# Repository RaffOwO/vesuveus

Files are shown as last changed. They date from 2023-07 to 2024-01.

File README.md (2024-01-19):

<p align="center" style="box-shadow: 0px 4px 8px rgba(0, 0, 0, 0.1);">
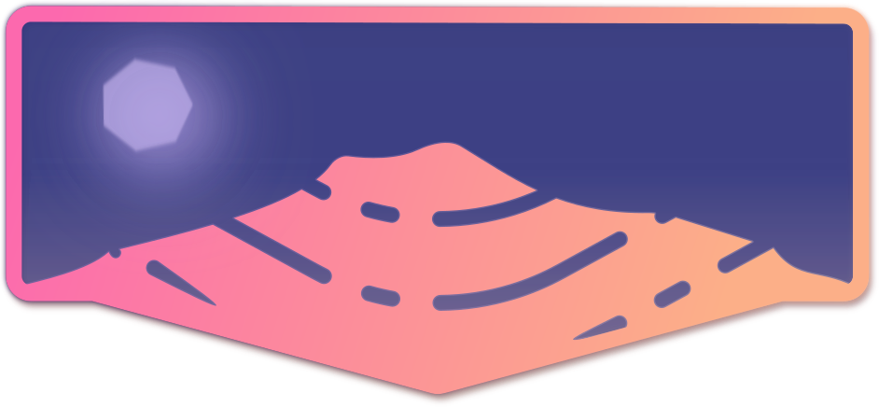
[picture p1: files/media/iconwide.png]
vesuveus keyboard
  
</p>

# Vesuveus - *Small*, yet *Mighty*, Mechanical Keyboard

Hey there! I present to you the Vesuveus, a small, ergonomic mechanical keyboard! 
It's carefully designed to be your trusty sidekick for every task, whether you're coding, designing, gaming or just having some typing fun.

This little wonder is heavily inspired by the [atreus](https://shop.keyboard.io/products/keyboardio-atreus), the _alice_
and many amazing works of the [community](https://reddit.com/r/ergomechkeyboards). 

  <p align="center" style="box-shadow: 0px 4px 8px rgba(0, 0, 0, 0.1);">
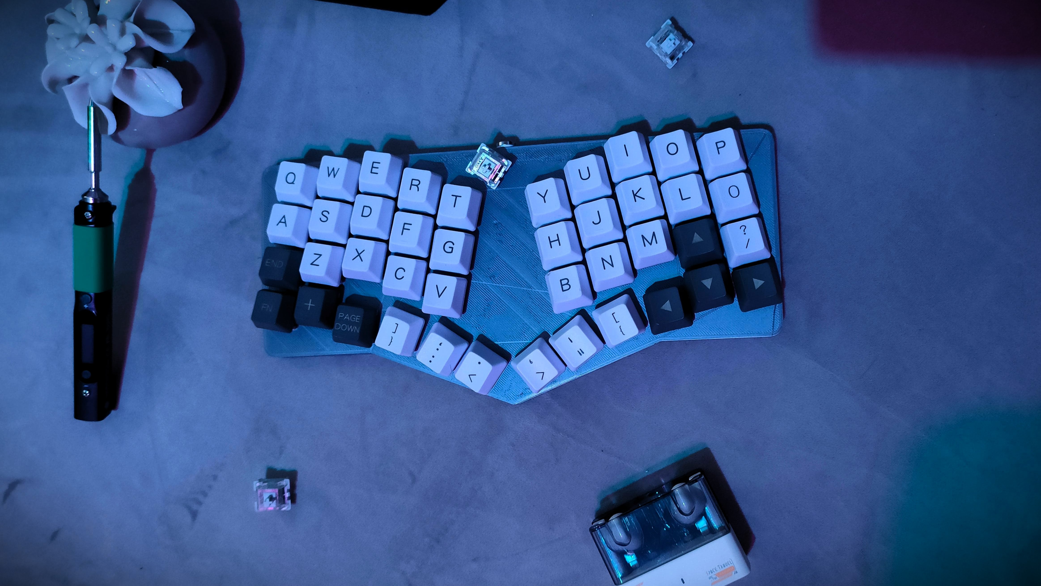
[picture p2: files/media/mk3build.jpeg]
     
  </p>

## The Design Principles

My fascination with mechanical keyboards has been ongoing since my initial encounter with the incredible works within the keyboard enthusiast community, over the past years I wanted to contribute by designing a keyboard that could serve as the initial stepping stone for many within this community. My goal was to bridge the gap between the familiar and the new, making a user-friendly and approachable option for all keyboard enthusiasts while striking a balance between ___affordability, ergonomics, usability, adaptability___.

Let's dive into the details of the design and see how I've achieved these goals!

  <p align="center" style="box-shadow: 0px 4px 8px rgba(0, 0, 0, 0.1);">
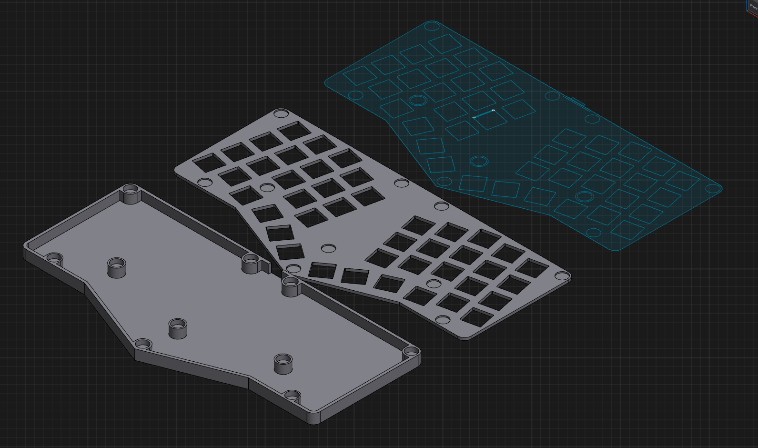
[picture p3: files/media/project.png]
     
  </p>

## Affordability:

One of the primary concerns associated with ergonomic mechanical keyboards is their price point. I understand that the cost can be intimidating, particularly when you're uncertain whether it will align with your workflow and preferences. That's why I've designed Vesuveus to be a cost-effective option for those who are curious about ergonomic keyboards and want to give them a try.

To get an estimate of your potential costs, consider the following components for your Vesuveus build:

- 42 switches.
- 42 1u keycaps. (You could also use the mx-flat keycap I designed, you can find the STL file in the [files/printables](./files/printables) folder).
- 42 diodes (1N4148).
- 14 circular magnets (8mm x 2mm).
- 1 MCU (I recommend an RP2040-Zero).
- 24 or 22 AWG Wire (or any wire).
- A 3D printed case (PLA or PETG), or the PCB when it becomes available.

My own build costed around 40-50€, but you can achieve an even lower cost if you already have some of these components on hand.

## Ergonomics:

As a full-time computer user, I find myself spending a significant amount of time typing, and I'm sure many of you can relate to that experience. That's precisely why I've prioritized ergonomics and comfort when designing Vesuveus, making it ideal for prolonged typing sessions. I've accomplished this by incorporating the following design elements:

- **Split Halves**: This feature widens the space between the two halves, promoting a more open and relaxed posture for the shoulders.
- **Angled Split**: A 12-degree angle between the split halves minimizes the outward angle of the wrists, reducing strain and discomfort during use.
- **Thumb Cluster & Stagger:**  The 48-degree thumb cluster and the columnar stagger ensure that our hands rest at a natural and comfortable angle. This thoughtful design minimizes stress on your hands and enhances the overall typing experience.

## Usability:

Usability is another key factor I've carefully considered when designing Vesuveus. Much of this focus centers around the keyboard layout, which I've crafted to be as intuitive and user-friendly as possible. Over the past years, I've experimented with various layouts, from 34 to 48 keys, and the 42-key layout has proven to be the ideal balance for me. Let me break it down for you:

- **34 or 36 layouts** are great for programmers and have a minimal footprint. However, they posed challenges when I needed to use mouse-centric apps like Inkscape or PowerPoint. I found myself missing essential modifier keys and an arrow cluster, which drove me to explore other options.
    
  <p align="center" style="box-shadow: 0px 4px 8px rgba(0, 0, 0, 0.1);">
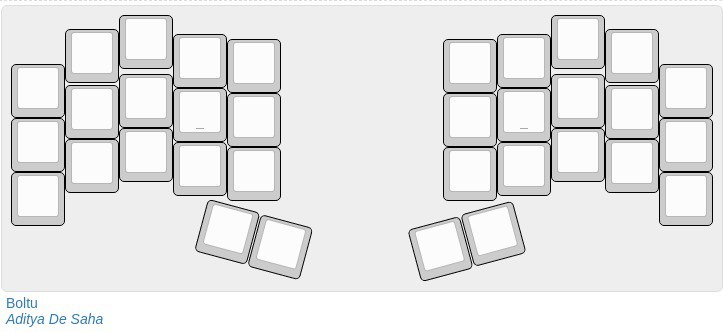
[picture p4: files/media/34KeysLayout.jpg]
34-KeysLayout
     
  </p>

  If you are interested in this layout I suggest the [bgkeeb](https://github.com/sadekbaroudi/bgkeeb) from sadekbaroudi and the [Sweep](https://github.com/davidphilipbarr/Sweep) by davidphilipbarr.

- On the other hand, **46 or 48 layouts** felt chaotic and ignored the ergonomic principles I valued. The need to have my pinky finger responsible for pressing 4 to 6 keys was impractical. Despite some creative workarounds, it just didn't feel right to me.

  <p align="center" style="box-shadow: 0px 4px 8px rgba(0, 0, 0, 0.1);">
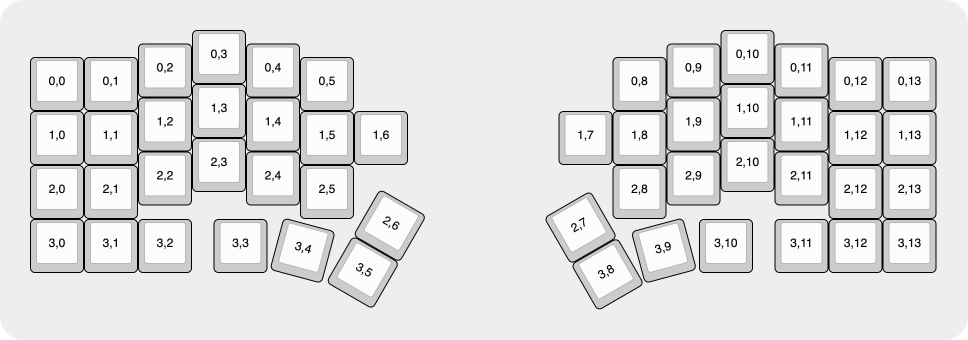
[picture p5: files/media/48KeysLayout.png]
48-KeysLayout
      
  </p>

  if you would like something the [Frame-48](https://github.com/gregsqueeb/Frame-48) by gregsqueeb is a great option.

So, this **42-key layout** provides the best of both worlds. It offers usability, comfort, and an efficient use of space. This layout strikes the perfect balance between usability, comfort, and dimensions. Additionally, it retains familiar shortcuts with the placement of modifier keys (CTRL, OS, ALT, etc.), and the arrow cluster is optimally positioned.

What makes this layout truly remarkable is the need to memorize only two layers, which are accessible by holding the thumb central and inner keys. This allows you to access the full 104 keys without shifting the essential keys, such as space, arrows, or modifiers. It's easy to learn and use, making it an excellent choice for those new to the world of ergonomic mechanical keyboards.

  <p align="center" style="box-shadow: 0px 4px 8px rgba(0, 0, 0, 0.1);">
      Layout
  </p>

  - **Note** - _common 42 layouts_: 
  
    There are other 42 layouts, but instead of placing the 3 switches along the bottom row, the they got an extra pinky column, which as I said before, I don't like. If you are interested in this layout I suggest the [piantor](https://github.com/beekeeb/piantor) from beekeeb.

  - **Note** - _extra pinky_: 

    I think that adding a extra side key for the pinky could be great (see the [TOTEM](https://github.com/GEIGEIGEIST/TOTEM) by GEIGEIGEIST layout) because we are accustomed to stretching the pinky sideways, but this would occupy more space on the desk and on the 3D printer, so I didn't feel to include that in this version. Maybe, in the future there will be a 44 keys version.

  - **Note** - _gaming_:
    
    When it comes to gaming, I've traditionally used the WASD keys for movement. However, due to the compact layout of Vesuveus, I've opted for the ESDF configuration instead. While this choice initially requires some configuration when installing a new game, it allows me to maintain my muscle memory. I experimented with a separate gaming layer but found it disrupted my workflow. This decision aims to preserve usability and minimize the learning curve, making Vesuvius versatile for various uses. Feel free to customize your layout as needed!

## Adaptability:

I've designed Vesuveus to be as adaptable as possible, software and hardware wise. Using KMK the keyboard can be configured to your liking, and the firmware can be easily modified to suit your needs. Also, the keyboard is designed to be compatible with a wide range of switches, keycaps, and other components. This adaptability allows you to customize your Vesuveus to your heart's content, making it a truly unique and personal keyboard.

# Vesuveus in Action
In this video, you can witness satisfying keystrokes of the Vesuveus mechanical keyboard. Please note that the video was recorded with a smartphone, so the quality might not be top-notch, but the typing experience is!

Vesuveus in Action (https://www.youtube.com/watch?v=dZ_lzMvHjn4)

Stay tuned for more videos and pictures of the Vesuveus in action as I continue to explore and improve this little wonder!

# Should You Try Vesuveus?

Hey, if my madness intrigues you, why not give Vesuveus a try? I'd be more than happy to include your contributions or ideas in this project! Feel free to get in touch, and let's make some keyboard magic together! 😄

**TO DO** build guide in the [files/README.md](./files/README.md) file.

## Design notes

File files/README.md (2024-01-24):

# You are in the directory: vesuveus/files

Here you can fine all the files that are used in the project, plus a build on how to build a vesuveus urself.

## Directory structure
- /`code`: This directory contains the code.py to use along kmk firmware.
    ---
- /`media`: This directory contains the images used in the README.md(s) file.
    ---
- /`printables`: This directory contains the printable STL/3MFs.
    ---
- /`production`: This directory contains the files used to produce the keyboard.
    ---
- /`README.md`: This file.
    ---

# How to build your own Vesuveus (WIP)

In the alternative-versions folder you can find some OLD versions and other revisions made by the community, always appreciated!

Note that this guide refers to the current version that you can find in 'files/printables' directory!

Also this section is a work in progress, I will update it as soon as I can. Next time I will build another one of this beauty I will take more pictures and videos to make the guide more complete.

### BOM (Bill of Materials)
What you need:

- 42 switches
   - any MX style switch will work

- 42 keycaps
    - any MX style keycap will work 

- 42 diodes
    - I used 1N4148 diodes, you can find them easily on Amazon or Aliexpress 

- 20 magnetic disks 8x2cm
    - I used [these](https://www.amazon.it/gp/product/B07Z5QZQZQ/ref=ppx_yo_dt_b_asin_title_o00_s00?ie=UTF8&psc=1) but you can use any other magnetic disk you want as long as they are 8cm in diameter and 2cm in height (or less)

- 1 MCU
    - I used a waveshare RP 2040 Zero, but you can use any other MCU you want as long is compatible with KMK and has at least 14 GPIO pins.

- the plate and the base (3D printed)
    - you can find the STL/3MF files in the 'files/printables' directory

- soldering equipment
    - a soldering iron, community alwasy suggest [pinecil](https://www.pine64.org/pinecil/), I always used a cheap one from Amazon and it worked just fine

    - soldering tin, I use 0.5mm tin but you can use any other tin you want

    - wires, I use 22 AWG wires but as always you can use any other wire you want

- strong glue
    - I used [this](https://www.amazon.it/gp/product/B07Z5QZQZQ/ref=ppx_yo_dt_b_asin_title_o00_s00?ie=UTF8&psc=1) but you can use any other glue you want as long as it's strong enough to keep the magnetic disks in place
    
- a lot of patience, love and passion (but if you are here you already have that 🤍)

# Build guide

## 1. Download the files
Clone the repository or download the zip file.

## 2. Print the case and plate
From the printables directory, print the case and the plate. 
I suggest you to use 3MF files, because I used the free version of Shapr3D to design the keyboard, and the 3MF files are more accurate than the STL files.

## 3. Clean the case and plate (optional)
Clean the case and plate from imperfections, i suggest to use some fine sandpaper.

## 4. Glue the magnets
Glue the magnets in the case and plate in the circular spots, the magnets should be flush with the surface.

**Tip:** Let the glue dry, don't try to put the plate and the case before the glue is dry, work with single part at a time.

## 5. Put the switches on the plate
Put the switches on the plate. the pins should face down, and the switch should be flush with the plate.

## 6. Prepare the diodes
Using a pair of tweezers, bend the diodes legs to make a circle and cut off the excess, then position the pin of the switch in the circle.

## 7. Prepare the pins
Solder a bit of soldering tin on the pins of the switches, this will help you to solder the diodes & wires.

## 8. Solder the diodes
Solder the diodes to the pins of the switches, make sure that the diodes are in the right direction, the black band should face the top.

## 9. Prepare the wires
Take the wires and cut them to the right length, then strip the ends of the wires.

## 10. Solder the wires
First, tin the wires, then solder them to the diodes, and the left pin of the switches.
The diodes are wired in rows, so the wires should be soldered in the same row of the diodes.
The switches left pin are wired in columns, so the wires should be soldered in the same column of the switches.

## 11. Prepare & Solder the MCU
Tin a bit the MCU pins, then solder the wires to the MCU.

## 12. Flash the MCU
Flash the MCU with the firmware of your choice, i suggest you to use KMK firmware with my keymap.

## 13. Finishing touches
Now you just need to put the plate and case together, also you can put some rubber feet on the case, and dont forget to put the keycaps on the switches.

## 14. Type your satisfaction
Now you can type your satisfaction, and enjoy your new keyboard.

### Video Guide (WIP)

[Vesuveus Build Guide!](https:/youtube.com/)

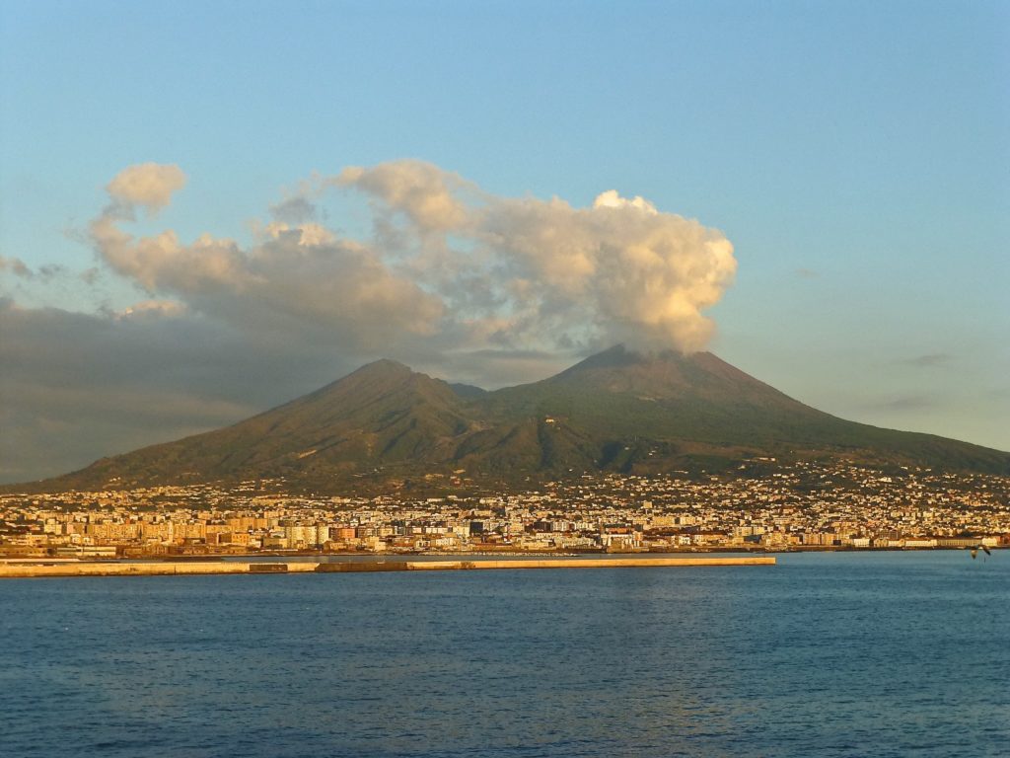
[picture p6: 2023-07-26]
files/media/vesuvius.jpg

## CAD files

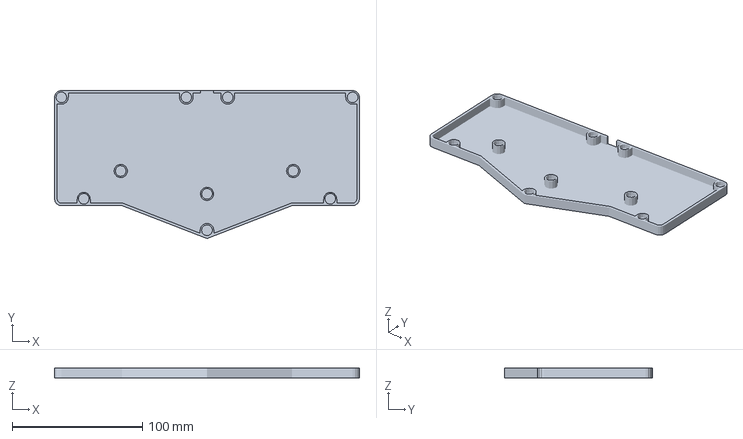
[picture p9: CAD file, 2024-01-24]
files/printables/Body.3mf
234.4 x 113.8 x 8.00 mm

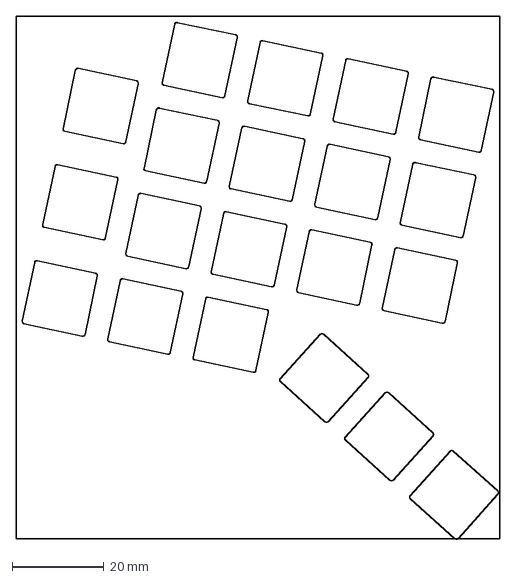
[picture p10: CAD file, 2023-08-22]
files/production/plate.dxf
105.5 x 114.0 mm

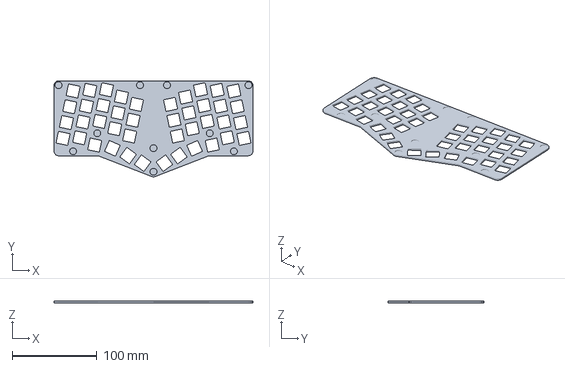
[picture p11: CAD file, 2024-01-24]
files/printables/Plate.3mf
234.4 x 113.6 x 2.00 mm

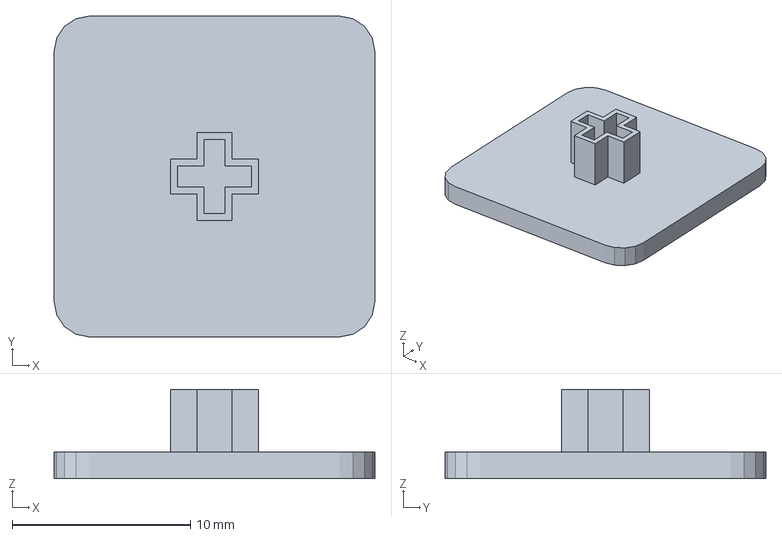
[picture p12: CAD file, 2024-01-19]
files/printables/Keycap18x18.3mf
18.0 x 18.0 x 5.00 mm

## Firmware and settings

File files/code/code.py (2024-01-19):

# Author: Raffaele Castellano
# Date: 2023-07-27
# Version: 2.3
# Description: KMK firmware for the vesuveus keyboard

# imports
import board
from kmk.kmk_keyboard import KMKKeyboard
from kmk.keys import KC
from kmk.scanners import DiodeOrientation
from kmk.modules.layers import Layers
from kmk.modules.holdtap import HoldTap
from kmk.modules.modtap import ModTap
from kmk.modules.mouse_keys import MouseKeys

# keyboard inizialization
keyboard = KMKKeyboard()

# pins
keyboard.col_pins = (board.GP11,board.GP10,board.GP9,board.GP8,board.GP7,board.GP6,board.GP5,board.GP4,board.GP3,board.GP2,board.GP1,board.GP0)
keyboard.row_pins = (board.GP12,board.GP13,board.GP14,board.GP15)
keyboard.diode_orientation = DiodeOrientation.COL2ROW

# modules
layers = Layers()
keyboard.modules.append(layers)

holdtap = HoldTap()
holdtap.tap_time = 300
keyboard.modules.append(holdtap)

modtap = ModTap()
keyboard.modules.append(modtap)

mousekeys = MouseKeys()
mousekeys.max_speed = 7
mousekeys.move_step = 0
mousekeys.scroll_step = 0
keyboard.modules.append(mousekeys)

# layers:
# tab on tap, layer1 on hold
TABL1 = KC.LT(1, KC.TAB, prefer_hold=True)
# delete on tap, layer1 on hold
DELL1 = KC.LT(1, KC.DEL, prefer_hold=True)
# tab on tap, layer2 on hold
TABL2 = KC.LT(2, KC.TAB, prefer_hold=True)
# esc on tap, layer2 on hold
ESCL2 = KC.LT(2, KC.ESC, prefer_hold=True)

# tapmod:
# spc on tap, shift on hold
SPCSFT = KC.HT(KC.SPC, KC.LSFT, prefer_hold=False)
# enter on tap, shift on hold
ENTSHF = KC.HT(KC.ENTER, KC.LSFT, prefer_hold=True)
# backspace on tap, shift on hold
BSPSHF = KC.HT(KC.BSPC, KC.LSFT, prefer_hold=True)

# layouts
# Q       W       E       R       T      ___     ___     Y       U       I       O       P
# A       S       D       F       G      ___     ___     H       J       K       L       ENTSHF
# LSFT    Z       X       C       V      ___     ___     B       N       M       UP      RSFT
# LCTL    LGUI    LALT    ESCL2   TAVL1  SPCSFT  BSPSHF  DELL1   TABL2   LEFT    DOWN    RIGHT
# --------------------------------------------------------------------------------
# `       [       ]       (       )      ___     ___     #       ~       &       '       \
# N1      N2      N3      N4      N5     ___     ___     N6      N7      N8      N9      N0
# LSFT    /       *       -       =      ___     ___     ,       .       ?       UP      RSFT
# LCTL    LGUI    LALT    ESCL2   TABL1  SPCSFT  BSPSHF  DELL1   TABL2   LEFT    DOWN    RIGHT
# --------------------------------------------------------------------------------
# F11     {       }       <       >      ___     ___     @       $       |       "       F12
# F1      F2      F3      F4      F5     ___     ___     F6      F7      F8      F9      F10
# LSFT    %       ^       _       +      ___     ___     ;       :       !       MUP     RSFT
# LCTL    LGUI    LALT    ESCL2   MLC    MRC     WHUP    WHDN    TABL2   MLEFT   MDOWN   MRIGHT
# --------------------------------------------------------------------------------


keyboard.keymap = [
    
    # ALPHA LAYER
    [KC.Q,      KC.W,       KC.E,       KC.R,       KC.T,       KC.NO,          KC.NO,      KC.Y,       KC.U,       KC.I,       KC.O,       KC.P,      
     KC.A,      KC.S,       KC.D,       KC.F,       KC.G,       KC.NO,          KC.NO,      KC.H,       KC.J,       KC.K,       KC.L,       ENTSHF, 
     KC.LSFT,   KC.Z,       KC.X,       KC.C,       KC.V,       KC.NO,          KC.NO,      KC.B,       KC.N,       KC.M,       KC.UP,      KC.RSFT,    
     KC.LCTL,   KC.LGUI,    KC.LALT,    ESCL2,      TABL1,      KC.SPC,         BSPSHF,     DELL1,      TABL2,      KC.LEFT,    KC.DOWN,    KC.RIGHT,],

    # NUM/SYM LAYER     
    [KC.GRV,    KC.LBRC,    KC.RBRC,    KC.LPRN,    KC.RPRN,    KC.NO,          KC.NO,      KC.HASH,    KC.TILD,    KC.AMPR,    KC.QUOT,    KC.BSLS,
     KC.N1,     KC.N2,      KC.N3,      KC.N4,      KC.N5,      KC.NO,          KC.NO,      KC.N6,      KC.N7,      KC.N8,      KC.N9,      KC.N0,
     KC.LSFT,   KC.SLSH,    KC.ASTR,    KC.MINS,    KC.EQL,     KC.NO,          KC.NO,      KC.COMM,    KC.DOT,     KC.QUES,    KC.UP,      KC.RSFT,
     KC.LCTL,   KC.LGUI,    KC.LALT,    ESCL2,      TABL1,      SPCSFT,         BSPSHF,     DELL1,      TABL2,      KC.LEFT,    KC.DOWN,    KC.RIGHT,],

    # FUN/SYM LAYER - MOUSE
    [KC.F11,    KC.LCBR,    KC.RCBR,    KC.LABK,    KC.RABK,    KC.NO,          KC.NO,      KC.AT,      KC.DLR,     KC.PIPE,    KC.DQUO,    KC.F12,
     KC.F1,     KC.F2,      KC.F3,      KC.F4,      KC.F5,      KC.NO,          KC.NO,      KC.F6,      KC.F7,      KC.F8,      KC.F9,      KC.F10,
     KC.LSFT,   KC.PERC,    KC.CIRC,    KC.UNDS,    KC.PLUS,    KC.NO,          KC.NO,      KC.SCLN,    KC.COLN,    KC.EXLM,    KC.MS_UP,   KC.RSFT,
     KC.LCTL,   KC.LGUI,    KC.LALT,    ESCL2,      KC.MB_LMB,  KC.MB_RMB,      KC.MW_UP,   KC.MW_DN,   TABL2,      KC.MS_LT,   KC.MS_DN,   KC.MS_RT,],

]

if __name__ == '__main__':
    keyboard.go()

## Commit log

2023-07-27 3D models of case and plate!
    [Plate.3mf, base.3mf]
2023-08-07 Schematics PDF
2023-08-08 created files sub-folders; uploaded layout and dxf
    [Basev2.3mf, Plate.3mf, Plate.stl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]
2023-08-08 uploaded the stls, dxf and svgs of the plate
    [Basev2.stl, Platev2.stl, vesuveusplatecutoutR12.dxf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]
2023-08-08 added 3 degree tenting bottom to top
    [Basev2.3mf, Basev2.stl]
2023-08-10 Case files uploaded
    [MrKrustyKrabFullCase.dxf, MrKrustyKrabFullCase.step, MrKrustyKrabFullCase.stl]
2023-08-11 Untested Gerbers
2023-08-21 perfected v1 version, released new version
    [Basev2.3mf, Basev2.stl, Icon.dxf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]
2023-08-21 Organization of Alternative versions
    [Basev2.3mf, Basev2.stl, MrKrustyKrabFullCase.dxf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]
2023-08-21 fixed readme, TO DO: broken product links
    [icon.dxf]
2023-08-22 icon updated, build guide moved in files/README.md
    [icon.dxf, plate.dxf]
2023-08-22 updated icon
    [iconv3.dxf]
2023-08-25 re-arranged files
    [Basev2.3mf, Basev2.stl, MrKrustyKrabFullCase.dxf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]
2023-08-31 new version, EOL for compact
    [Base.3mf, Base.stl, KalihMXLP-plate.dxf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]
2023-08-31 alternative staggered version
    [Base.3mf, Base.stl, KLP-plate.dxf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]
2023-09-01 Created unique version
    [Base.3mf, Base.stl, Basev2.3mf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]
2023-10-12 Archived OLD version
    [Base.stl, MX-plate.dxf, Plate.3mf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]
2023-10-17 Updated Version - Bluetooth testing
    [19x19-Plate.dxf, Base.3mf, BaseHex.3mf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]
2023-10-18 newlayout - to update layout draw.io
    [Base.3mf, BaseHex.3mf, Plate.3mf]
2023-10-24 Vesuveus 3.0 Released
    [Base.3mf, Body.3mf, Plate.3mf]
2023-11-03 update 2.9 - preparation for 3.0 full release
    [19x19-Plate.dxf]
2023-11-29 more holes in the kbd!
    [19x19-Plate.dxf, BodyAngled.3mf, Plate.3mf]
2024-01-19 Update: Icon, Layout, and Printables
    [Body.3mf, BodyAngled.3mf, Keycap18x18.3mf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]
2024-01-19 deleted old versions
    [Base.stl, MX-plate.dxf, MrKrustyKrabFullCase.dxf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]
2024-01-24 Last update
    [19x19-Plate.dxf, Body.3mf, Plate.3mf]
